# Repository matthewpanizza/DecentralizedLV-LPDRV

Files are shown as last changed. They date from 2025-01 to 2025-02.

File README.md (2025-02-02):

# DecentralizedLV-LPDRV
Software Repository for Low Power Driver Board

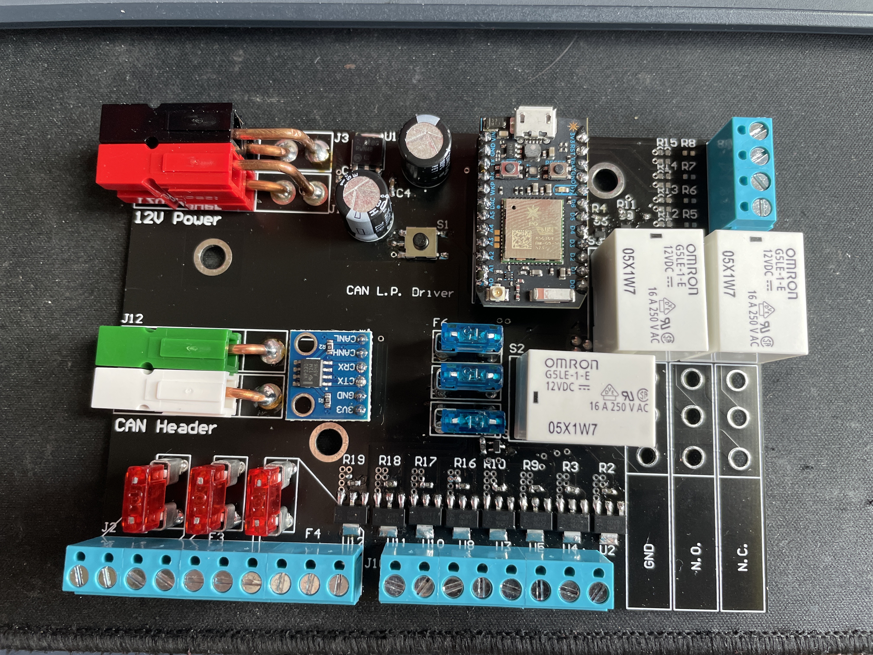
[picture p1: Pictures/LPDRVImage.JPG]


## Project Overview

The DecentralizedLV Low-Power Driver Board (LPDRV) has the primary role of powering the accessories in the vehicle. One LPDRV board is placed on each corner of the vehicle and is connected to accessory components such as lights, cooling fans, and cooling pumps. It determines if those are accessories should be powered based on CAN Bus messages it receives from the [DecentralizedLV Dash Controller](https://github.com/matthewpanizza/DecentralizedLV-DashController) and [DecentralizedLV Power Controller](). See the main [DecentralizedLV-Documentation](https://github.com/matthewpanizza/DecentralizedLV-Documentation) repository for information about the DecentralizedLV system and how to set up the software environment for programming this board.

## Block Diagram
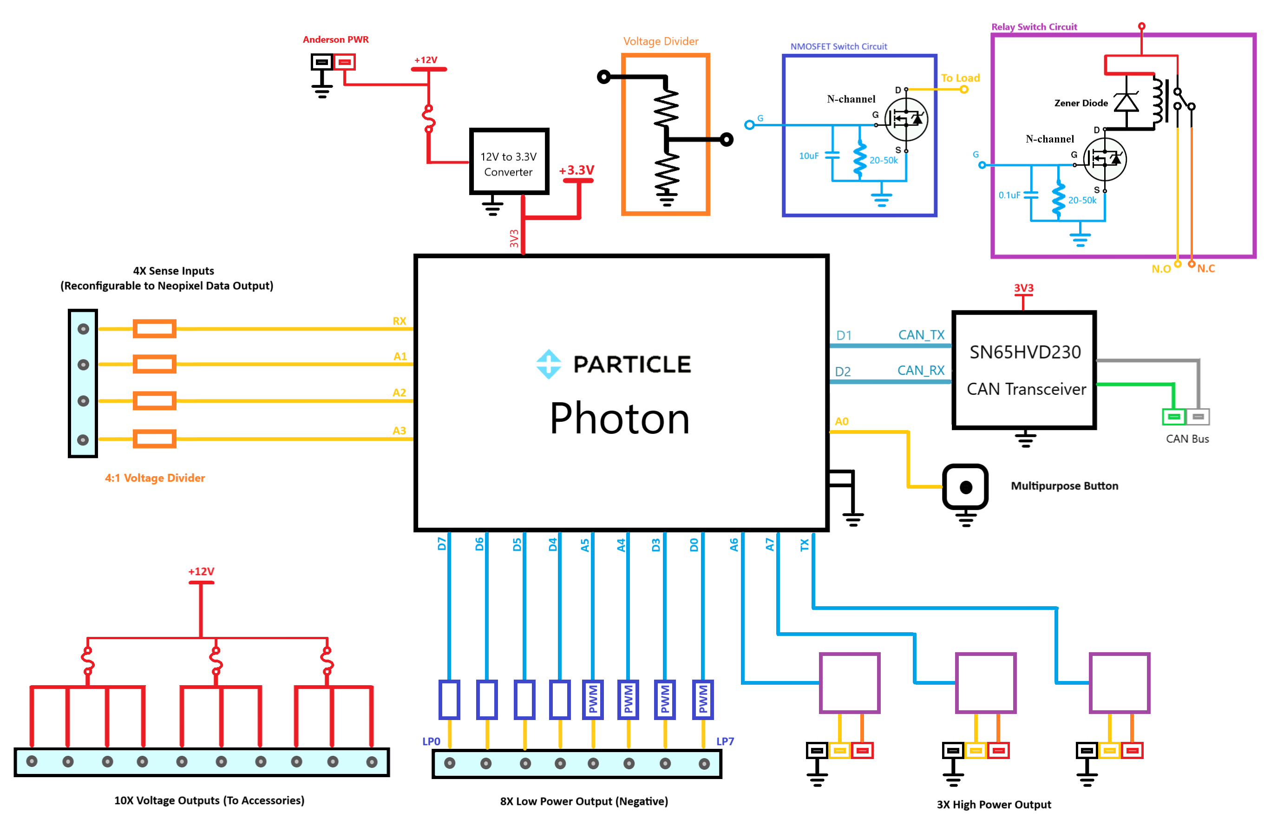
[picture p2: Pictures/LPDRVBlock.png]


## Hardware Capabilities
- 4X PWM-Capable [Low-power driver pins](https://github.com/matthewpanizza/DecentralizedLV-Documentation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) (A5, A4, D3, D0) (N-MOSFET Configuration)
- 4X Non-PWM [Low-power driver pins](https://github.com/matthewpanizza/DecentralizedLV-Documentation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) (D7, D6, D5, D4) (N-MOSFET Configuration)
- 3X fused [High-power driver pins](https://github.com/matthewpanizza/DecentralizedLV-Documentation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) (A6, A7, RX) with Normally-Open and Normally-Closed output connectors.
- 4X [Sense Pins](#https://github.com/matthewpanizza/DecentralizedLV-Documentation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) (4:1 voltage divider ratio)
- [Neopixel](https://github.com/matthewpanizza/DecentralizedLV-Documentation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) Data Output
- 10X fused 12V passthrough header to connect positive terminal of low-power accessories
- Multipurpose push-button

## Important Roles
- Responsible for distributing power received from the Power Controller to the majority of accessory components (lights, pumps, fans) in the low-voltage electrical system
- Has the capability to read in 12V signals using [Sense Pins](#https://github.com/matthewpanizza/DecentralizedLV-Documentation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) and passing that information to other places in the vehicle
- Controls [Neopixel LED Strips](https://github.com/matthewpanizza/DecentralizedLV-Documentation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) that are used as turn signals and brake lights

### CAN Bus Communication

CAN Bus communication is handled using the [DecentralizedLV-Boards API](https://github.com/matthewpanizza/DecentralizedLV-Boards) submodule for sending and receiving messages. The submodule also has the CAN message encoding and decoding for this board and other boards in the system. Check out the [Boards API LPDRV section](https://github.com/matthewpanizza/DecentralizedLV-Boards?tab=readme-ov-file#lpdrv_rearleft_can) for the CAN message encoding. Check out the [DecentralizedLV-Documentation](https://github.com/matthewpanizza/DecentralizedLV-Documentation) repository for information about CAN Bus communication.

### Neopixel Control (with Sense Pin Jumper Bypass)

There are hardware outputs on this board to allow for control of a Neopixel RGB LED strip. Most Neopixels require a 5-Volt power supply, but you can use one of the [High-power driver pins](https://github.com/matthewpanizza/DecentralizedLV-Documentation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) to attach a 12V to 5V regulator.

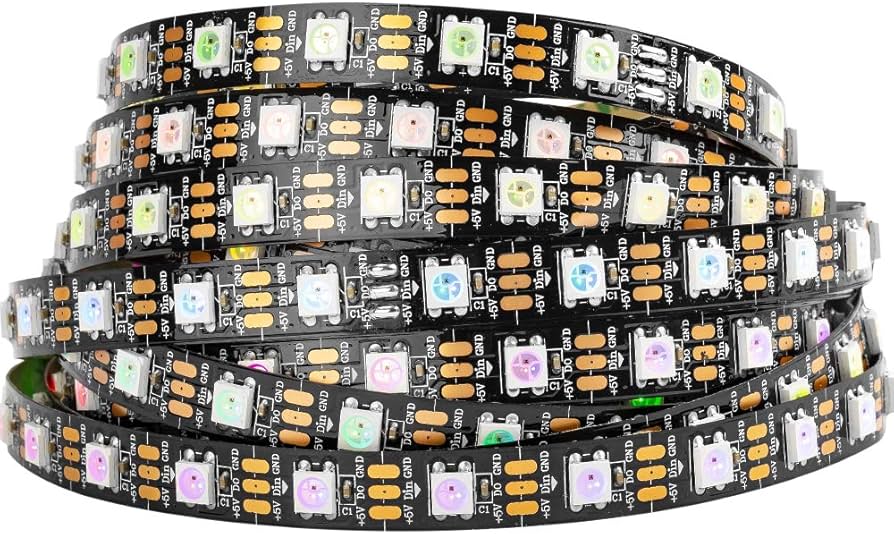
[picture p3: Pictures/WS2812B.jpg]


These strips can be obtained for < [$20 on Amazon](https://www.amazon.com/s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) and have different options for density of the LEDs. Pictured is a 60 LED/meter strip, but full density of 144 LEDs/meter would be recommended. 

**Important**: In order to use Neopixel control, you must directly pass the microcontroller pin to the Sense Pin terminal block. This is done by removing the respective resistor (R5, R6, R7, R8) and connecting the two pads directly with solder. See the PCB boardview below for the positions of the mentioned resistors.

### PCB Schematic / Boardview

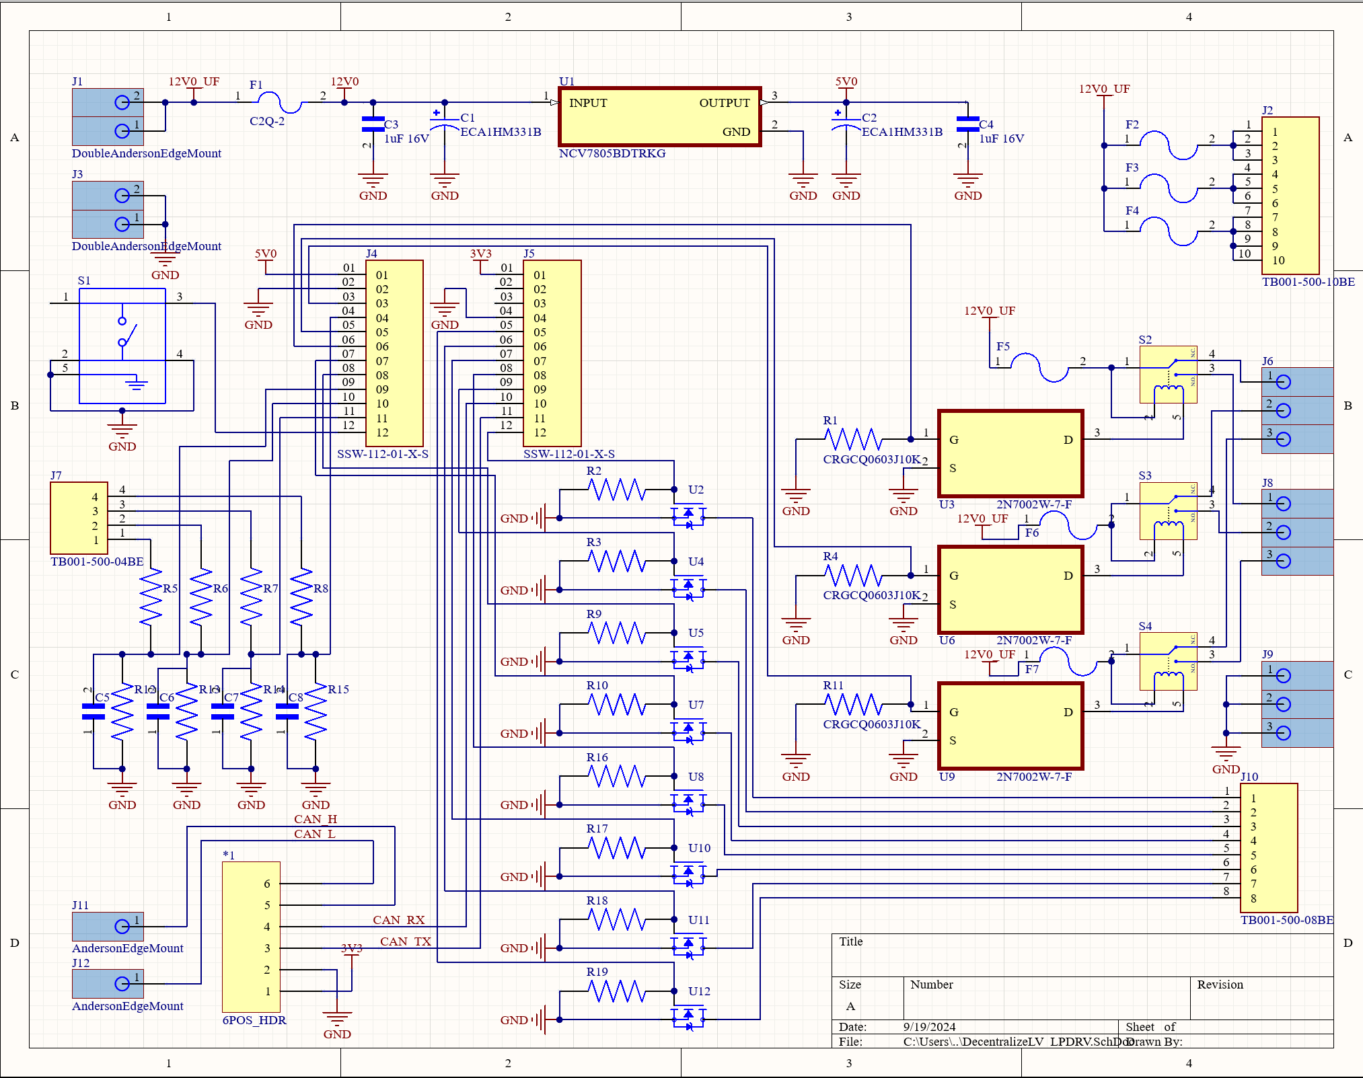
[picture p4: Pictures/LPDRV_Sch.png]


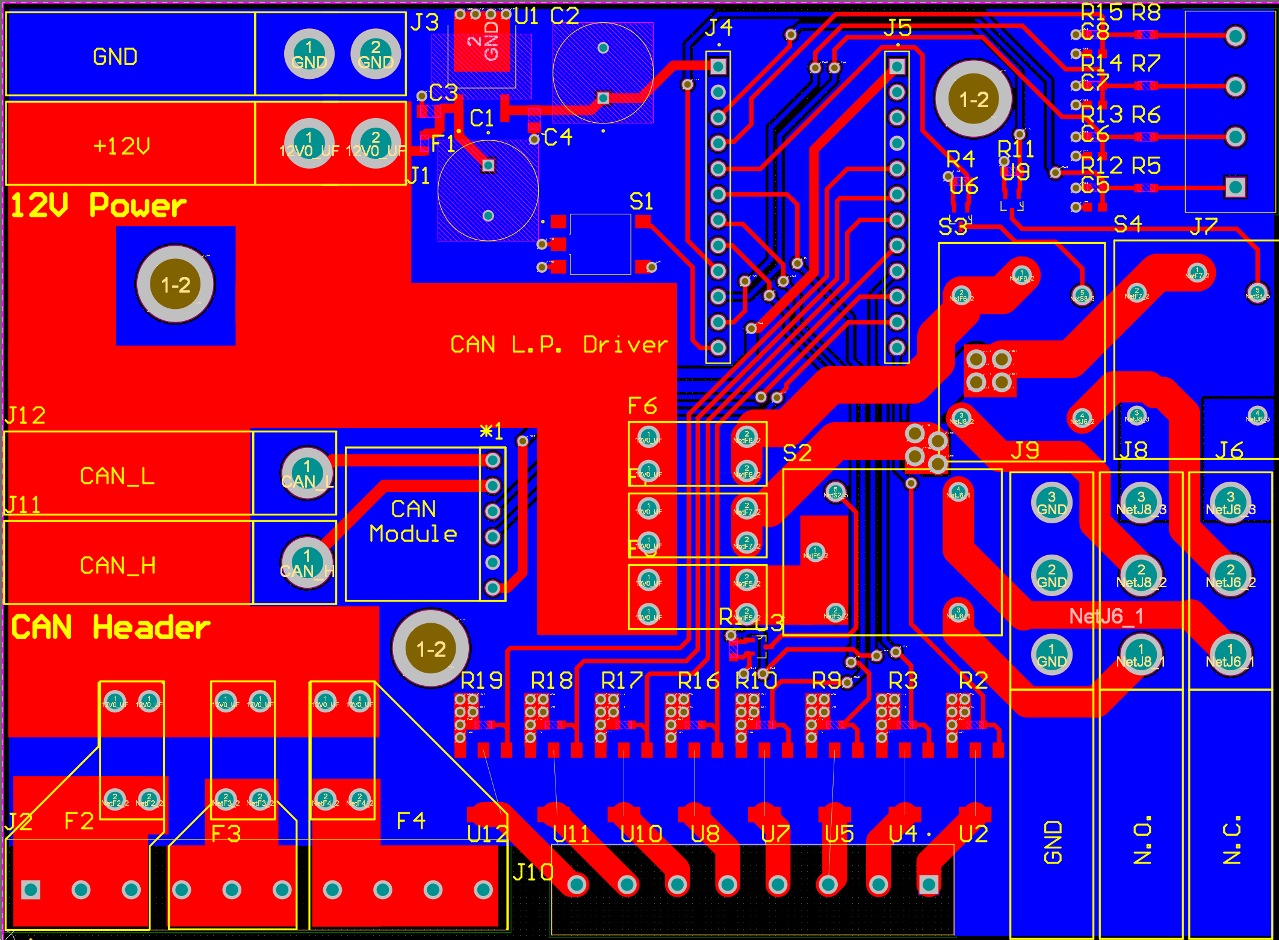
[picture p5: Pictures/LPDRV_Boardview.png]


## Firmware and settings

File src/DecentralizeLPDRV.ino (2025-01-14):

/*
 * Project DecentralizeLPDRV
 * Description: Code for the Decentralized Low-Voltge System Low-Power Driver Boards
 * Author: Matthew Panizza
 * Date: May 7, 2022
 */
#include "neopixel.h"   //Neopixel Library for Addressable Strips
#include "DecentralizedLV-Boards/DecentralizedLV-Boards.h"

/////////////////////////////////////////////////////////
// BOARD DEFINITION - UNCOMMENT BOARD TO BE PROGRAMMED //
/////////////////////////////////////////////////////////

#define BDFL      //Front-Left Board
//#define BDFR      //Front-Right Board
//#define BDRL      //Rear-Left Board
//#define BDRR        //Rear-Right Board

/////////////////////////////////////////////////////////
/////////////      PIN MAPPINGS      ////////////////////
/////////////////////////////////////////////////////////

#define LP7     D0      //Low Power Output 7 (PWM)
#define LP6     D3      //Low Power Output 6 (PWM)
#define LP5     A4      //Low Power Output 5 (PWM)
#define LP4     A5      //Low Power Output 4 (PWM)
#define LP3     D4      //Low Power Output 3 
#define LP2     D5      //Low Power Output 2
#define LP1     D6      //Low Power Output 1
#define LP0     D7      //Low Power Output 0 

#define HP2     TX      //High Power Output 2
#define HP1     A7      //High Power Output 1
#define HP0     A6      //High Power Output 0

#define IP3     RX      //Multipurpose IO Pin 3
#define IP2     A1      //Multipurpose IO Pin 2
#define IP1     A2      //Multipurpose IO Pin 1 
#define IP0     A3      //Multipurpose IO Pin 0


/////////////////////////////////////////////////////////////////////////
// Neopixel Board Params   Allows Per-Board Pixel Count and Pin Config //
/////////////////////////////////////////////////////////////////////////

#ifdef BDFL
    #define PIXEL_COUNT 36
    #define PIXEL_PIN RX
#endif
#ifdef BDFR
    #define PIXEL_COUNT 36
    #define PIXEL_PIN RX
#endif
#ifdef BDRL
    #define PIXEL_COUNT 46
    #define PIXEL_PIN A2
#endif
#ifdef BDRR
    #define PIXEL_COUNT 1
    #define PIXEL_PIN A1
#endif

//////////////////////////////////////////////////////////////////////////////
// Neopixel Setup Params - Allows Control of LED Type, and if LEDs are used //
//////////////////////////////////////////////////////////////////////////////

#define USING_NEOPIXEL      //Uncomment if Neopixels are being used
#define PIXEL_TYPE WS2812B

//RGB color definitions for various LED colors
#define AMBER 255,60,0      // R = 255, G = 60, B = 0
#define WHITE 255,200,180
#define DARK 0,0,0

#define FLASH_PIXEL_WIDTH   14      //Number of pixels wide the BPS flash indicator should be
#define SOL_PUL_CYCLES      500     //Delay between solar animation pulses
#define SOL_PUL_WIDTH       1       //Number of pixels in the animation at full-brightness
#define SOL_FADE_WID        3       //Number of pixels in the animation where there is fade-out
#define SOL_FADE_OFFSET     30      //Amount of dimming that occurs for each fade step from the center
#define STRT_FADE_OFFSET    60
#define TRN_DELAY           30      //Milliseconds between publishes of transmission gear

#ifdef USING_NEOPIXEL
Adafruit_NeoPixel strip = Adafruit_NeoPixel(PIXEL_COUNT, PIXEL_PIN, PIXEL_TYPE);    //Create Neopixel Strip Object
#endif

////////////////////////////
// CAN Message Formatting //
////////////////////////////

CAN_Controller canController;

LPDRV_RearLeft_CAN rearLeftDriver(REAR_LEFT_DRIVER);

DashController_CAN dashController(DASH_CONTROL_ADDR);

PowerController_CAN powerController(POWER_CONTROL_ADDR);

LV_CANMessage inputMessage;    //Input message for receiving from multiple addresses and filtering

bool flashOn = true;        //Flash flag if there is a BMS fault
bool startupHDL;            //Flag set to 1 when car is first turned on to play animations

bool startupToggle = true;  //Flag for playing neat animations on startup
uint8_t animationMode;      //Global for the current animation mode
uint16_t animationTick;     //A counter that makes animation have very little overhead - change the state of the LED based on the counter value

Timer pTimer(10, animationHandler);     //Create a timer that happens ever 10 milliseconds for updating the animations
Timer pTimer2(250, animationHandler2);  //A timer for the LV board that handles flashing the BPS fault light

//Misc control-flow variables
uint32_t loop_time = 0;

void boardConfig();     //Function prototype
void transmitLPDRVBoards();
void updateOutputPins();
void updateInputPins();
void updateAnimations();

SYSTEM_MODE(SEMI_AUTOMATIC);    //Disable Wi-Fi for this system

//Function runs once at power up to configure the device.
void setup() {
    canController.begin(500000);
    canController.addFilter(powerController.boardAddress);   //Allow incoming messages from Power Controller
    canController.addFilter(dashController.boardAddress);    //Allow incoming messages from Dash Controller
    boardConfig();              //Call function to configure the pins depending on which board this is
    rearLeftDriver.initialize();    //Reset the underlying object flags
    #ifdef USING_NEOPIXEL       //If neopixel is being used on this board, initialize the strip
    strip.begin();
    #endif
    animationMode = 0;          //Reset animation mode to default, set the tick to 0
    animationTick = 0;
    updateOutputPins();         //Update the pin state based on the data received from other boards
    updateInputPins();          //Update this board's variables that are set by reading the input pins
    pTimer.start();             //start the timer for the animations
    
}

//Loop continuously executes as fast as possible
void loop() {
    //All of the fancy pin logic may be complicated but makes life in the loop real EZ
    while(canController.receive(inputMessage)){      //If a CAN Message was received from another board matching the filter (ID 0x100)
        dashController.receiveCANData(inputMessage);
        powerController.receiveCANData(inputMessage);
    }
    updateOutputPins();         //Update the pin state based on the data received from other boards
    updateInputPins();          //Read the multipurpose pins that need to be transmitted from this board
    updateAnimations();

    while(millis()-loop_time < 10) delayMicroseconds(1);    //Fancy delay mechanism which takes into account time to read CAN bus frames
    loop_time = millis();

    transmitLPDRVBoards();      //Transmits data from this board to the CAN Bus.
}

/// @brief Call the sendCANData for the respective LPDRV board you've programmed.
void transmitLPDRVBoards(){
    #ifdef BDFL //Front-Left Driver Board
        //Haven't made a Front Left Driver class in Boards API yet. Will need to make one if you want to transmit data from this board.
    #endif
    #ifdef BDFR //Front-Right Driver Board
        //Haven't made a Front Right Driver class in Boards API yet. Will need to make one if you want to transmit data from this board.
    #endif
    #ifdef BDRL
        rearLeftDriver.sendCANData(canController);
    #endif
    #ifdef BDRR
        //Haven't made a Rear Right Driver class in Boards API yet. Will need to make one if you want to transmit data from this board.
    #endif
    
}

//AnimationHandler updates the states of LEDs and other things that play animations over time - using an interrupt allows loop() to continue to run and get updates
void animationHandler(){
    #ifdef BDFL //Front-Left Driver Board Config
        if(animationMode == 0){    //Neopixel animated, turn signal not animated
            if(dashController.leftTurnPWM){   //Flag set true when there is a left turn signal active
                if(animationTick == PIXEL_COUNT) return;    //If we've reached the length of the strip, we've lighted all of the pixels
                strip.setPixelColor(animationTick++,AMBER); //Light pixel # animation tick AMBER, then increment the counter so the next pixel is lit the next time the interrupt runs
                strip.show();   //Call show to update the LED strip
            }
            else{   //If the turn signal is turned off, turn off all of the pixels in the strip
                strip.clear();
                strip.show();
                animationTick = 0;  //Reset the counter so we start at the beginning of the strip again
            }
        }
        else if(animationMode == 1){
            if(dashController.leftTurnPWM){
                byte gCol = animationTick*0.85;
                byte bCol = animationTick*0.75;
                for(int i = 0; i < PIXEL_COUNT; i++) strip.setPixelColor(i, animationTick,gCol, bCol);
                strip.show();
                if(animationTick < 255) animationTick++;
            }
            else{
                animationTick = 0;
            }
        }
        else if(animationMode == 2){
            uint16_t tempTick  = (animationTick >> 2);
            if(tempTick < (PIXEL_COUNT) + SOL_FADE_WID + 1){
                strip.setPixelColor(tempTick-SOL_FADE_WID-1,0,0,0);
                for(int i = 0; i < SOL_PUL_WIDTH; i++){
                    strip.setPixelColor(tempTick-1+i,255,255,255);
                }
                for(int i = 0; i < SOL_FADE_WID; i++){
                    strip.setPixelColor(tempTick+SOL_PUL_WIDTH-1+i,255-STRT_FADE_OFFSET*(i+1),255-STRT_FADE_OFFSET*(i+1),255-STRT_FADE_OFFSET*(i+1));
                    strip.setPixelColor(tempTick-i,255-STRT_FADE_OFFSET*(i+1),255-STRT_FADE_OFFSET*(i+1),255-STRT_FADE_OFFSET*(i+1));
                }
                strip.show();
                animationTick++;
            }
            else if(tempTick < (PIXEL_COUNT << 1) + SOL_FADE_WID + 1){
                uint8_t pixNum = PIXEL_COUNT-1-(tempTick-(PIXEL_COUNT));
                strip.setPixelColor(pixNum,255,255,255);
                strip.show();
                animationTick++;
            }
            else{
                startupToggle = false;
                animationMode = 0;
                animationTick = 0;
            }
        }
    #endif
    #ifdef BDFR //Front-Right Driver Board Config
        if(animationMode == 0){    //Chase animation - fills strip starting at pixel 0
            if(dashController.rightTurnPWM){    //If the right turn signal is on
                if(animationTick == PIXEL_COUNT) return;
                strip.setPixelColor(animationTick++,AMBER);
                strip.show();
            }
            else{
                strip.clear();
                strip.show();
                animationTick = 0;
            }
        }
        else if(animationMode == 1){    //Fade-up entire strip animation
            if(dashController.rightTurnPWM){
                byte gCol = animationTick*0.85;
                byte bCol = animationTick*0.75;
                for(int i = 0; i < PIXEL_COUNT; i++) strip.setPixelColor(i, animationTick,gCol, bCol);
                strip.show();
                if(animationTick < 255) animationTick++;
            }
            else{
                animationTick = 0;
            }
            
        }
        else if(animationMode == 2){    //Startup animation - small group of pixels travelling across strip
            uint16_t tempTick  = (animationTick >> 2);
            if(tempTick < (PIXEL_COUNT) + SOL_FADE_WID + 1){
                strip.setPixelColor(tempTick-SOL_FADE_WID-1,0,0,0);
                for(int i = 0; i < SOL_PUL_WIDTH; i++){
                    strip.setPixelColor(tempTick-1+i,255,255,255);
                }
                for(int i = 0; i < SOL_FADE_WID; i++){
                    strip.setPixelColor(tempTick+SOL_PUL_WIDTH-1+i,255-STRT_FADE_OFFSET*(i+1),255-STRT_FADE_OFFSET*(i+1),255-STRT_FADE_OFFSET*(i+1));
                    strip.setPixelColor(tempTick-i,255-STRT_FADE_OFFSET*(i+1),255-STRT_FADE_OFFSET*(i+1),255-STRT_FADE_OFFSET*(i+1));
                }
                strip.show();
                animationTick++;
            }
            else if(tempTick < (PIXEL_COUNT << 1) + SOL_FADE_WID + 1){
                uint8_t pixNum = PIXEL_COUNT-1-(tempTick-(PIXEL_COUNT));
                strip.setPixelColor(pixNum,255,255,255);
                strip.show();
                animationTick++;
            }
            else{
                startupToggle = false;
                animationMode = 0;
                animationTick = 0;
            }
        }
    #endif
    #ifdef BDRL
        if(!rearLeftDriver.bmsFaultInput && !rearLeftDriver.switchFaultInput){   //No fault
            if(powerController.BrakeSense){   //If the brake pedal is pressed
                if(flashOn){ //If the white section of the BPS fault is ON, turn back to RED since fault was cleared
                    for(int i = 0; i < FLASH_PIXEL_WIDTH>>1; i++){
                        strip.setPixelColor((PIXEL_COUNT>>1)+i,255,0,0);
                        strip.setPixelColor((PIXEL_COUNT>>1)-1-i,255,0,0);
                    }
                    strip.show();
                    flashOn = 0;
                }
                if(animationTick < (PIXEL_COUNT>>1)){   //Do animation where the pixels start from the center and fill going outwards
                    strip.setPixelColor((PIXEL_COUNT>>1)+1+animationTick,255,0,0);
                    strip.setPixelColor((PIXEL_COUNT>>1)-animationTick,255,0,0);
                    strip.show();
                    animationTick++;
                }
            }
            else{   //Not braking
                if(flashOn){    //If the white section of the BPS fault is ON, turn OFF since fault was cleared
                    for(int i = 0; i < FLASH_PIXEL_WIDTH>>1; i++){
                        strip.setPixelColor((PIXEL_COUNT>>1)+i,0,0,0);
                        strip.setPixelColor((PIXEL_COUNT>>1)-1-i,0,0,0);
                    }
                    strip.show();
                    flashOn = 0;
                }
                if((powerController.ACCharge || powerController.SolarCharge) && !powerController.Ign){    //Animation for car charging/solar charging mode
                    uint16_t tempTick  = (animationTick >> 2);
                    if(tempTick < (PIXEL_COUNT >> 1) + SOL_FADE_WID + 1){
                        strip.setPixelColor((PIXEL_COUNT>>1)+tempTick-SOL_FADE_WID-1,0,0,0);
                        strip.setPixelColor((PIXEL_COUNT>>1)-tempTick+SOL_FADE_WID,0,0,0);
                        if(powerController.ACCharge && !powerController.SolarCharge){      //Charging from both solar and wall
                            for(int i = 0; i < SOL_PUL_WIDTH; i++){
                                strip.setPixelColor((PIXEL_COUNT>>1)+tempTick-1+i,100,0,100);
                                strip.setPixelColor((PIXEL_COUNT>>1)-tempTick-i,100,0,100);
                            }
                            for(int i = 0; i < SOL_FADE_WID; i++){
                                strip.setPixelColor((PIXEL_COUNT>>1)+tempTick+SOL_PUL_WIDTH-1+i,100-SOL_FADE_OFFSET*(i+1),0,100-SOL_FADE_OFFSET*(i+1));
                                strip.setPixelColor((PIXEL_COUNT>>1)+tempTick-i,100-SOL_FADE_OFFSET*(i+1),0,100-SOL_FADE_OFFSET*(i+1));
                                strip.setPixelColor((PIXEL_COUNT>>1)-tempTick-SOL_PUL_WIDTH-i,100-SOL_FADE_OFFSET*(i+1),0,100-SOL_FADE_OFFSET*(i+1));
                                strip.setPixelColor((PIXEL_COUNT>>1)-tempTick-1+i,100-SOL_FADE_OFFSET*(i+1),0,100-SOL_FADE_OFFSET*(i+1));
                            }
                        }
                        else if(powerController.SolarCharge && !powerController.ACCharge){     //Solar charging but not car charging
                            for(int i = 0; i < SOL_PUL_WIDTH; i++){
                                strip.setPixelColor((PIXEL_COUNT>>1)+tempTick-1+i,0,100,0);
                                strip.setPixelColor((PIXEL_COUNT>>1)-tempTick-i,0,100,0);
                            }
                            for(int i = 0; i < SOL_FADE_WID; i++){
                                strip.setPixelColor((PIXEL_COUNT>>1)+tempTick+SOL_PUL_WIDTH-1+i,0,100-SOL_FADE_OFFSET*(i+1),0);
                                strip.setPixelColor((PIXEL_COUNT>>1)+tempTick-i,0,100-SOL_FADE_OFFSET*(i+1),0);
                                strip.setPixelColor((PIXEL_COUNT>>1)-tempTick-SOL_PUL_WIDTH-i,0,100-SOL_FADE_OFFSET*(i+1),0);
                                strip.setPixelColor((PIXEL_COUNT>>1)-tempTick-1+i,0,100-SOL_FADE_OFFSET*(i+1),0);
                            }
                        }
                        else{   //Wall charging but not solar charging
                            for(int i = 0; i < SOL_PUL_WIDTH; i++){
                                strip.setPixelColor((PIXEL_COUNT>>1)+tempTick-1+i,100,0,100);
                                strip.setPixelColor((PIXEL_COUNT>>1)-tempTick-i,100,0,100);
                            }
                            for(int i = 0; i < SOL_FADE_WID; i++){
                                strip.setPixelColor((PIXEL_COUNT>>1)+tempTick+SOL_PUL_WIDTH-1+i,100-SOL_FADE_OFFSET*(i+1),100-SOL_FADE_OFFSET*(i+1),100-SOL_FADE_OFFSET*(i+1));
                                strip.setPixelColor((PIXEL_COUNT>>1)+tempTick-i,100-SOL_FADE_OFFSET*(i+1),100-SOL_FADE_OFFSET*(i+1),100-SOL_FADE_OFFSET*(i+1));
                                strip.setPixelColor((PIXEL_COUNT>>1)-tempTick-SOL_PUL_WIDTH-i,100-SOL_FADE_OFFSET*(i+1),100-SOL_FADE_OFFSET*(i+1),100-SOL_FADE_OFFSET*(i+1));
                                strip.setPixelColor((PIXEL_COUNT>>1)-tempTick-1+i,100-SOL_FADE_OFFSET*(i+1),100-SOL_FADE_OFFSET*(i+1),100-SOL_FADE_OFFSET*(i+1));
                            }
                        }
                        strip.show();
                        animationTick++;
                    }
                    else{
                        if(animationTick < SOL_PUL_CYCLES) animationTick++;
                        else animationTick = 0;
                    }
                    return;
                }
                if(animationTick >= 0){
                    strip.setPixelColor((PIXEL_COUNT>>1)+1+animationTick,0,0,0);
                    strip.setPixelColor((PIXEL_COUNT>>1)-animationTick,0,0,0);
                    strip.show();
                    if(animationTick)animationTick--;
                }
            }
        }
        else{   //Animation if there is a fault happening
            if(powerController.BrakeSense){   //Is the brake pressed at the same time? 
                for(int i = FLASH_PIXEL_WIDTH>>1; i < PIXEL_COUNT; i++){    //Light up pixels surrounding BPS flash area as RED
                    strip.setPixelColor((PIXEL_COUNT>>1)+i,255,0,0);
                    strip.setPixelColor((PIXEL_COUNT>>1)-1-i,255,0,0);
                }
            }
            else{   //Otherwise turn off LEDs surrounding the BPS flasher
                for(int i = FLASH_PIXEL_WIDTH>>1; i < PIXEL_COUNT; i++){
                    strip.setPixelColor((PIXEL_COUNT>>1)+i,0,0,0);
                    strip.setPixelColor((PIXEL_COUNT>>1)-1-i,0,0,0);
                }
            }
            if(flashOn){    //If the flasher variable is true, light up the section white. Variable toggled every 0.25 seconds by interrupt
                for(int i = 0; i < FLASH_PIXEL_WIDTH>>1; i++){
                    strip.setPixelColor((PIXEL_COUNT>>1)+i,255,200,170);
                    strip.setPixelColor((PIXEL_COUNT>>1)-1-i,255,200,170);
                }
            }
            else{
                for(int i = 0; i < FLASH_PIXEL_WIDTH>>1; i++){
                    strip.setPixelColor((PIXEL_COUNT>>1)+i,0,0,0);
                    strip.setPixelColor((PIXEL_COUNT>>1)-1-i,0,0,0);
                }
            }
            strip.show();
            
        }
    #endif
    #ifdef BDRR
        
    #endif
}

void animationHandler2(){
    flashOn = !flashOn; //Simply toggle the variable every time the interupt happens to make the section flash

}

void boardConfig(){
    //Low Power Outputs (J10)
    pinMode(LP7, OUTPUT);
    pinMode(LP6, OUTPUT);
    pinMode(LP5, OUTPUT);
    pinMode(LP4, OUTPUT);
    pinMode(LP3, OUTPUT);
    pinMode(LP2, OUTPUT);
    pinMode(LP1, OUTPUT);
    pinMode(LP0, OUTPUT);

    pinMode(HP2, OUTPUT);
    pinMode(HP1, OUTPUT);
    pinMode(HP0, OUTPUT);

    #ifdef BDFL //Front-Left Driver Board Config
        
        //pinMode(IP3, INPUT);      //Don't set this value if using it for the neopixels. Pin RX is being used for neopixel currently.
        pinMode(IP2, INPUT);
        pinMode(IP1, INPUT);
        pinMode(IP0, INPUT);
        
    #endif
    #ifdef BDFR //Front-Right Driver Board Config
       
        //pinMode(IP3, INPUT);      //Don't set this value if using it for the neopixels. Pin RX is being used for neopixel currently.
        pinMode(IP2, INPUT);
        pinMode(IP1, INPUT);
        pinMode(IP0, INPUT);

    #endif
    #ifdef BDRL

        //pinMode(IP3, INPUT);      //Don't set this value if using it for the neopixels. Pin RX is being used for neopixel currently.
        pinMode(IP2, INPUT);
        pinMode(IP1, INPUT);
        pinMode(IP0, INPUT);

    #endif
    #ifdef BDRR

        pinMode(IP3, INPUT);
        pinMode(IP2, OUTPUT);       //Fan PWM Output
        //pinMode(IP1, INPUT);      //Don't set this value if using it for the neopixels. Pin A1 is being used for neopixel currently.
        pinMode(IP0, INPUT);

    #endif
    
    pinMode(A0, INPUT_PULLUP);  //General-purpose button
}
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

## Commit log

2022-10-25 Added PCB docs
    [DecentralizeLC_LPDRV.GBL, DecentralizeLC_LPDRV.GBO, DecentralizeLC_LPDRV.GBP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]
2024-09-04 Add changes for reading transmission gear on GTI
2025-01-14 Add MCP_CAN_RK library, update to use newest Boards API calls. Update examples for transmitting switch state from a LPDRV
2025-01-14 Added macro selection for board transmission
